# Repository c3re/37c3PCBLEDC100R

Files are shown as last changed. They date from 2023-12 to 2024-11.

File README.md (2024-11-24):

# 37c3PCBLEDC100R
Coaster for your drinks with option for LED and microcontroller upgrade.
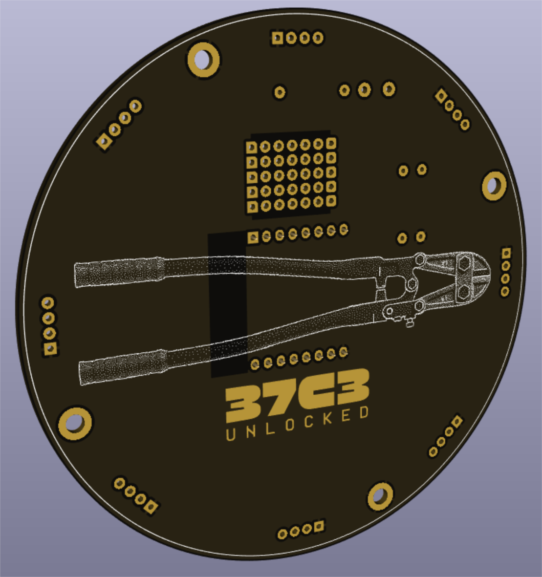
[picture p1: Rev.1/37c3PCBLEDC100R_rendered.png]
rendering of the 37c3PCBLEDC100R

## Rev.1
### Electrical connections
Important: Do not power the board by USB and an external power supply at the same time!
The Din pin of the first LED is connected to pin D4 (GPIO2) of the Wemos D1 mini. Two of the mounting holes are connected to GND, two of the holes are connected to 5V. You can use this feature to stack multiple 37c3PCBLEDc100R Boards with brass spacers.
### Bug
The revision 1 contains an error in the PCB-Layout! The error affects all LED footprints, the LED pins 1 & 2 are swapped. To fix the Bug, we recommend to bend pin 2 around the PCB edge and solder it on the bottom to the squared pad.
rendering of the 37c3PCBLEDC100R
## Rev.2
Bugfixed 
## License
The 37c3 Logo and the dithered image of the bolt cutter were created by Robokid // Luis F. Masallera and Euler Void \
37c3PCBLEDC100R © 2023 by c3RE is licensed under CC BY 4.0. To view a copy of this license, \
visit http://creativecommons.org/licenses/by/4.0/

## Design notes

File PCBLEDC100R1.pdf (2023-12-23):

## Rev.1

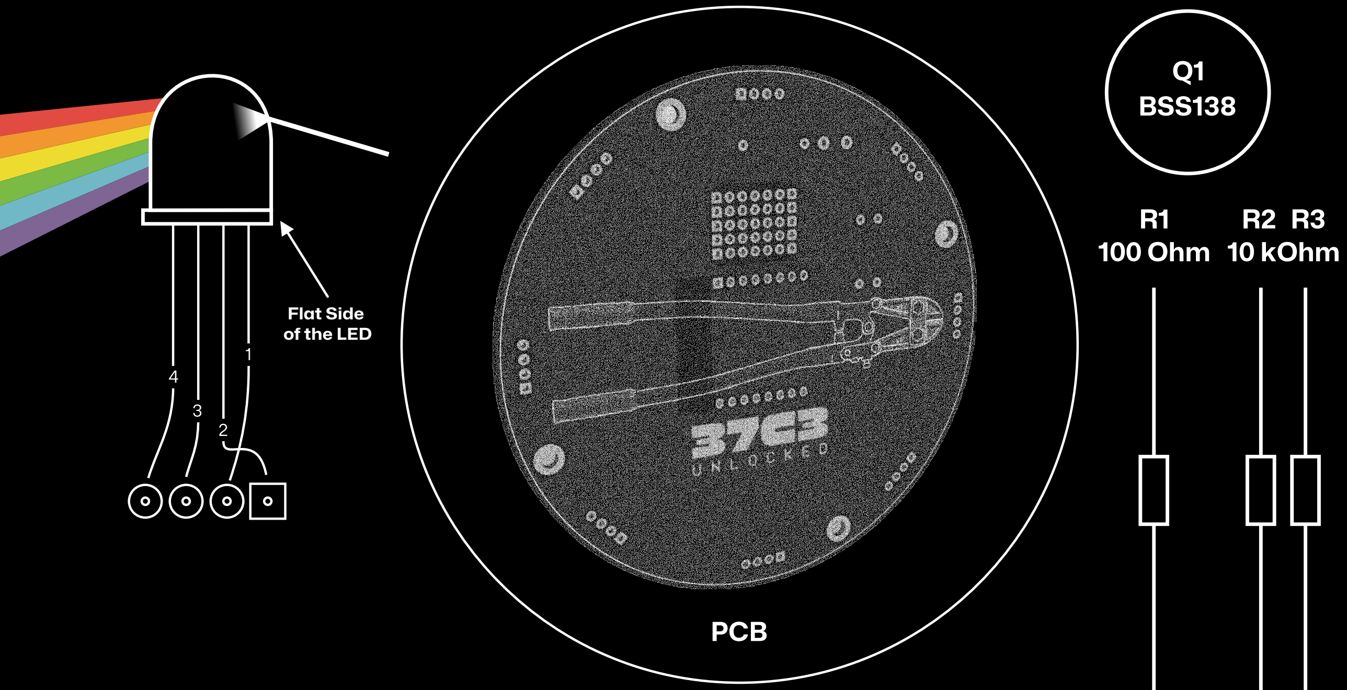
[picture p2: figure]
PCB; R2 R3 10 kOhm; R1 100 Ohm; Q1 BSS138; Flat Side of the LED

### 1. Solder Q1 to the PCB 2. Solder R1 - R3 to the PCB

3. Solder the Wemos D1 mini onto the PCB.
This is optional, you can also use an external microcontroller connected to Pad Din
4. Solder the LEDs to the Board.
Important: The PCB-Layout has an error.
Pin 1 & 2 are reversed.
LED Pin No. 1 is located at the flat side of the LED and
has to be connected to the pad next to the squared pad. Pin 2 has to be connected to the squared pad (see picture).

37c3

D1-D8
WS2812D-F5-1261

optional: WEMOS D1 mini

LICENCE:
The 37c3 Logo and the dithered bolt cutter were made by Robokid // Luis F. Masallera and Euler Void
37C3 PCBLEDC100R
© 2023 by c3RE is licensed under CC BY 4.0

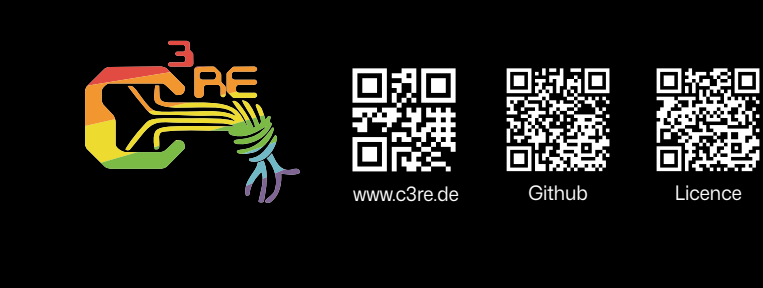
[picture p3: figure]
www.c3re.de; Github; Licence

To view a copy of this license, visit http://creativecommons.org/licenses/by/4.0/Github-Repo:
https://github.com/c3re/37c3PCBLEDC100R/

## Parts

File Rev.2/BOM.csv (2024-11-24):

Pos. | Qty. | Designator | Description | Manufacturer | Part-No. (Manufacturer) | Vendor | Part-No. (Vendor)
1 | 1 | R1 | Metal Film Resistor 100Ohm 250mW | VICO | MF1/4W-100Ω±1%-OT52 | LCSC | C2903231
2 | 2 | R2-R3 | Metal Film Resistors 10kΩ 250mW | YAGEO | MFR-25FTE52-10K | LCSC | C172967
3 | 1 | Q1 | MOSFET N-CH 50V 220mA SOT-23 | KUU | BSS138 | LCSC | C3015220
4 | 8 | D1-D8 | D=5mm RGB LED(Built-in IC) | Worldsemi | WS2812D-F5 | LCSC | C190565
5 | 4 | na | Spacer | Shuntian | M3X25+6 | LCSC | C775782

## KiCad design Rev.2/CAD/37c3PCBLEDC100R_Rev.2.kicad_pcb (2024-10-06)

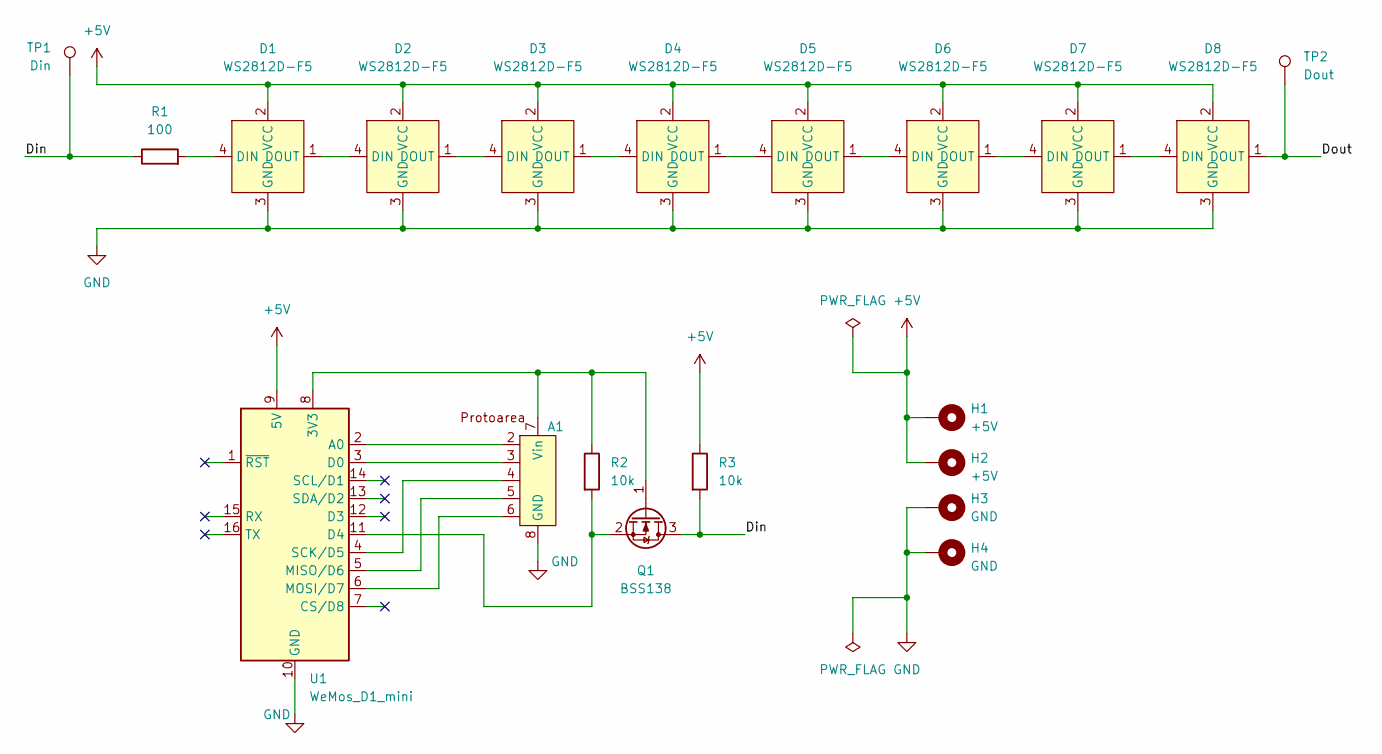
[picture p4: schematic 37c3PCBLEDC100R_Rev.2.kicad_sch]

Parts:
A1: Protoarea
D1, D2, D3, D4, D5, D6, D7, D8: WS2812D-F5; WS2812_THT; LCSC Part # C190565
H1, H2: +5V; MountingHole_3.2mm_M3_DIN965_Pad
H3, H4: GND; MountingHole_3.2mm_M3_DIN965_Pad
Q1: BSS138; SOT-23
R1: 100; 1206_combi_handsolder
R2, R3: 10k; 1206_combi_handsolder
TP1: Din; TestPoint_THTPad_D2.5mm_Drill1.2mm
TP2: Dout; TestPoint_THTPad_D2.5mm_Drill1.2mm
U1: WeMos_D1_mini; WEMOS_D1_mini_light

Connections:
+5V: D1.2 (VCC), D2.2 (VCC), D3.2 (VCC), D4.2 (VCC), D5.2 (VCC), D6.2 (VCC), D7.2 (VCC), D8.2 (VCC), H1.1, H2.1, R3.1, U1.9 (5V)
/Din: Q1.3 (D), R1.1, R3.2, TP1.1; also elsewhere on the board
/Dout: D8.1 (DOUT), TP2.1; also elsewhere on the board
GND: A1.8 (GND), D1.3 (GND), D2.3 (GND), D3.3 (GND), D4.3 (GND), D5.3 (GND), D6.3 (GND), D7.3 (GND), D8.3 (GND), H3.1, H4.1, U1.10 (GND)
unnamed: A1.7 (Vin), Q1.1 (G), R2.1, U1.8 (3V3)
unnamed: D1.4 (DIN), R1.2
unnamed: D1.1 (DOUT), D2.4 (DIN)
unnamed: D2.1 (DOUT), D3.4 (DIN)
unnamed: D3.1 (DOUT), D4.4 (DIN)
unnamed: D4.1 (DOUT), D5.4 (DIN)
unnamed: D5.1 (DOUT), D6.4 (DIN)
unnamed: D6.1 (DOUT), D7.4 (DIN)
unnamed: D7.1 (DOUT), D8.4 (DIN)
unnamed: Q1.2 (S), R2.2, U1.11 (D4)
unnamed: A1.2, U1.2 (A0)
unnamed: A1.3, U1.3 (D0)
unnamed: A1.5, U1.5 (MISO/D6)
unnamed: A1.6, U1.6 (MOSI/D7)
unnamed: A1.4, U1.4 (SCK/D5)

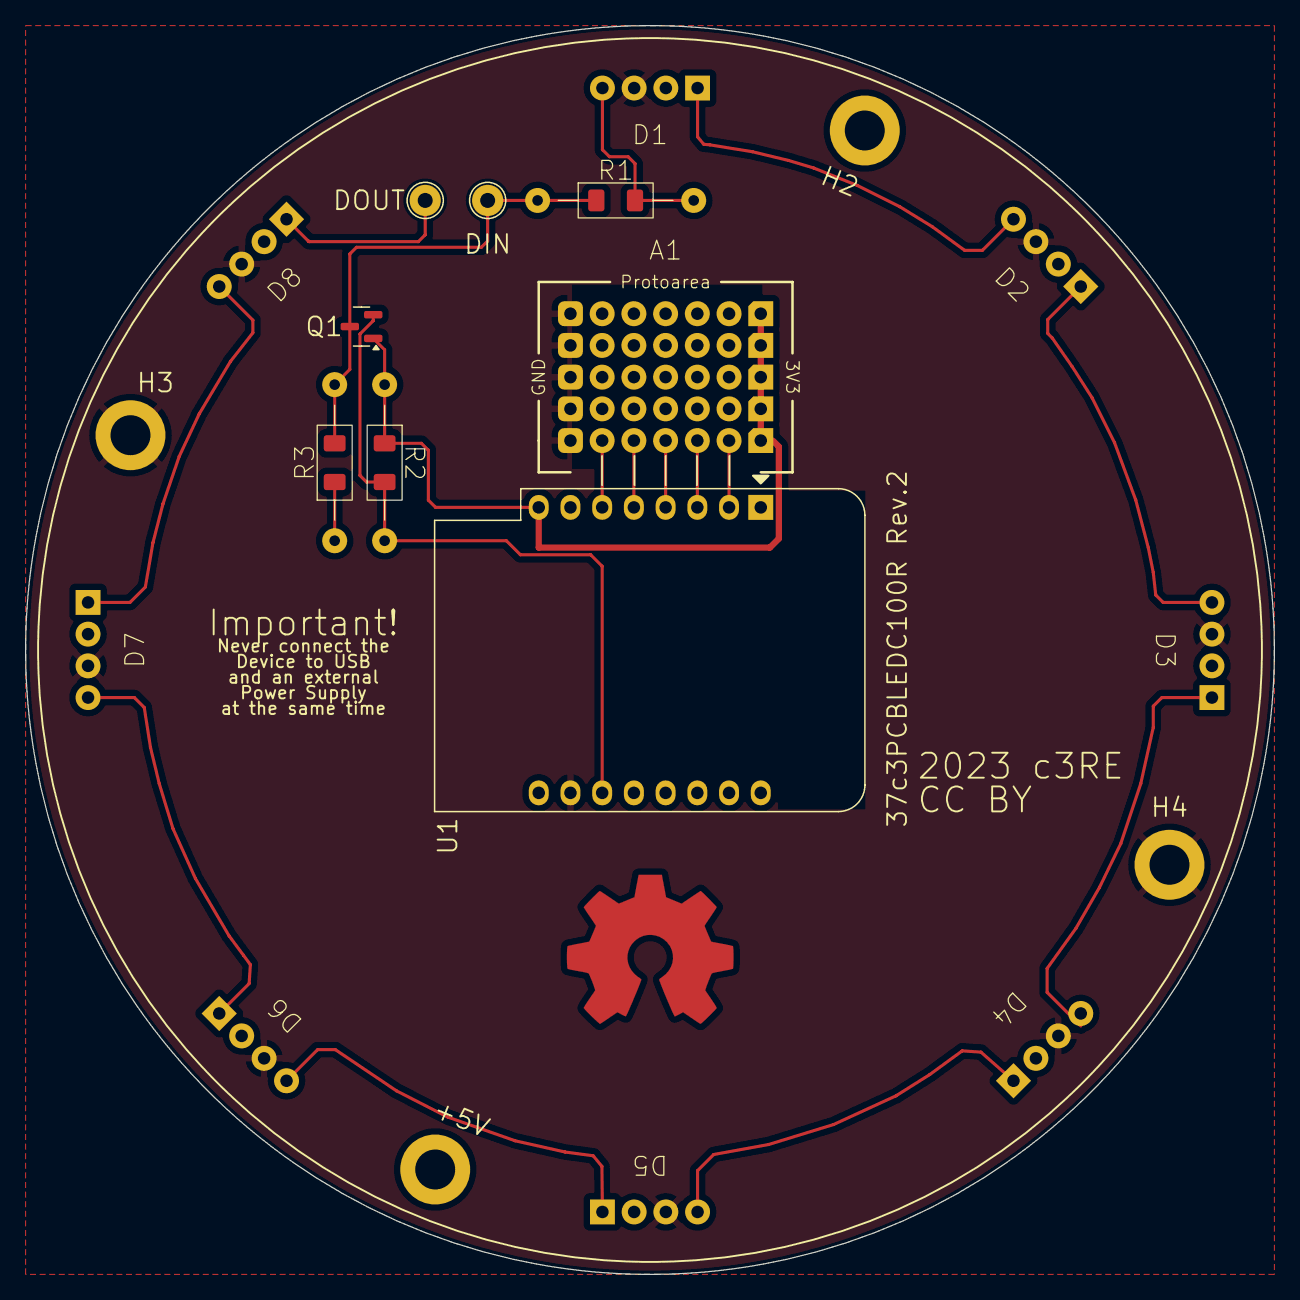
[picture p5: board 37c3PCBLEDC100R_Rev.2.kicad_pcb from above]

Board: 2 copper layers, 100.0 x 100.0 mm, 20 parts (0 on the bottom side), 19 nets.

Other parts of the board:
DIN: Din; TestPoint_THTPad_D2.5mm_Drill1.2mm
DOUT: Dout; TestPoint_THTPad_D2.5mm_Drill1.2mm

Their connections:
/Din: DIN.1; also elsewhere on the board
/Dout: DOUT.1; also elsewhere on the board

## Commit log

2023-12-23 Added assembly instructions
2024-01-07 Bugfixed Rev.2 added
    [37c3PCBLEDC100R_Rev.1.kicad_pcb, 37c3PCBLEDC100R_Rev.1.kicad_sch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]
2024-10-06 Updated Libs & changes on Top Silkscreen
    [37c3PCBLEDC100R_Rev.2-B_Cu.gbr, 37c3PCBLEDC100R_Rev.2-B_Mask.gbr, 37c3PCBLEDC100R_Rev.2-B_Paste.gbr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]
2024-10-06 Generated new Gerber-Files
2024-10-30 Create PARTS with components to buy and solder
2024-11-24 BOM revised
    [BOM.csv]
